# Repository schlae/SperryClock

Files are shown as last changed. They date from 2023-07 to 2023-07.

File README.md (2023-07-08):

# Nine Digit Sperry Neon Display Clock

Here's a cute little clock I designed that uses a Sperry neon display -- sometimes known as a Panaplex display. Please note this is not a fully completed project. Although I fabbed out boards and got the display working, I never got around to finishing the firmware.

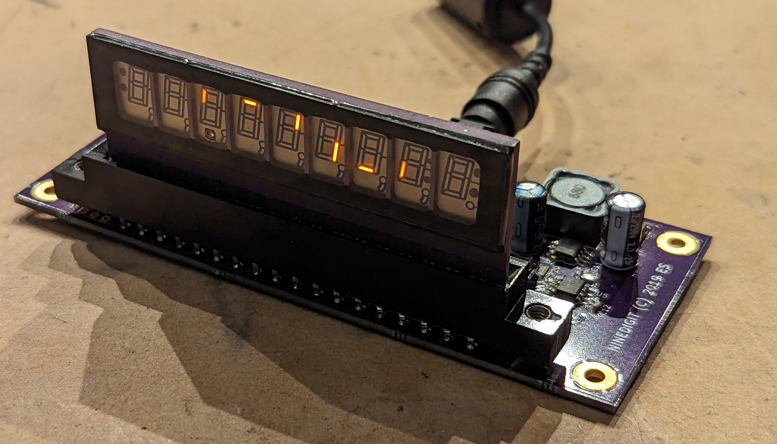
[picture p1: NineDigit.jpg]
A small circuit board with a Panaplex display plugged in


The particular display in this clock is a Sperry SP-425-09, but the basic design will probably work with other Panaplex displays as well.

The brains of the operation is an ATMega328P with a 16MHz crystal. You can load it with the Arduino bootloader and write programs for it using the Arduino IDE, or you can program it directly using avr-gcc, AVR Libc, and avrdude.

[Here is the schematic.](https://github.com/schlae/SperryClock/blob/main/NineDigit.pdf)

The basic design uses 9 transistors to multiplex the segment signals to each of the digits in the display. Typical Panaplex displays must be multiplexed otherwise the segment cathode material will start to plate out and darken the display, so avoid operating the display with just a single digit turned on continuously.

The [firmware](https://github.com/schlae/SperryClock/blob/main/NineDigit.ino) is incomplete but does include all the code required to drive the multiplexed display.

Still to be done:

* Driver for the DS3231
* Button handling
* Clock logic 

## Fabrication and Assembly Notes
This is a two-layer board, outer dimensions of 115mm x 50mm. 

The Sperry display should be installed in a socket. I've specified a part from EDAC but you might be able to find a cheaper one. The pin spacing is 0.156" (3.96mm).

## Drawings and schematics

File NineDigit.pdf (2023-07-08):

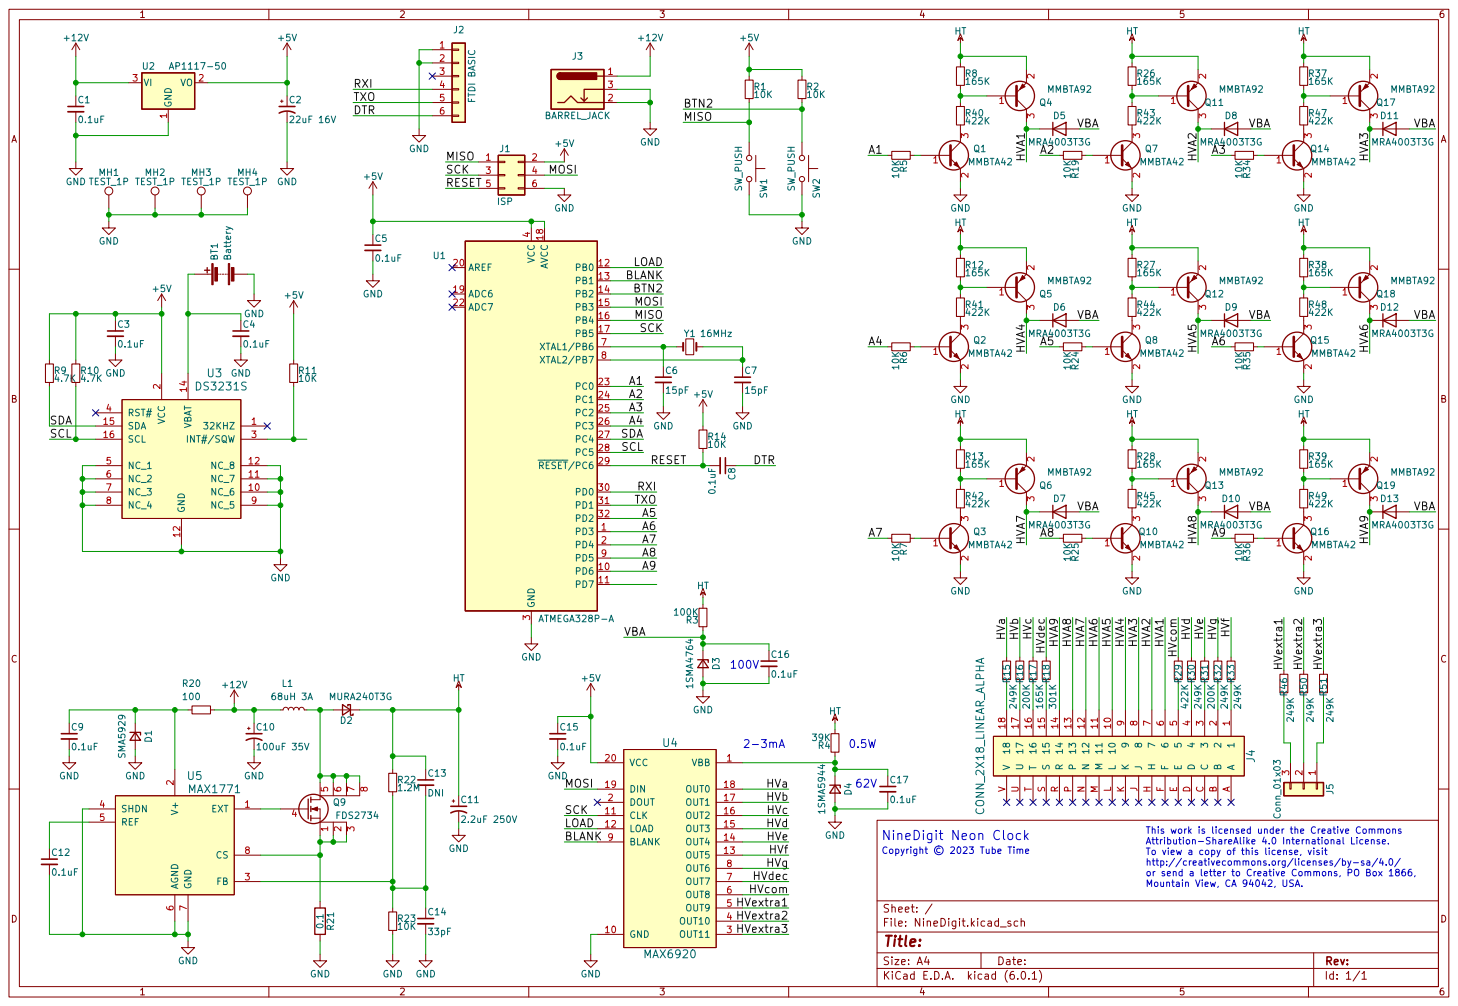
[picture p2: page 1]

http://creativecommons.org/licenses/by-sa/4.0/ or send a letter to Creative Commons, PO Box 1866, Mountain View, CA 94042, USA. þÿCopyright © 2023 Tube Time 0.5W

2 FB 3 SHDN 4 REF 5 AGND

This work is licensed under the Creative Commons Attribution-ShareAlike 4.0 International License. To view a copy of this license, visit

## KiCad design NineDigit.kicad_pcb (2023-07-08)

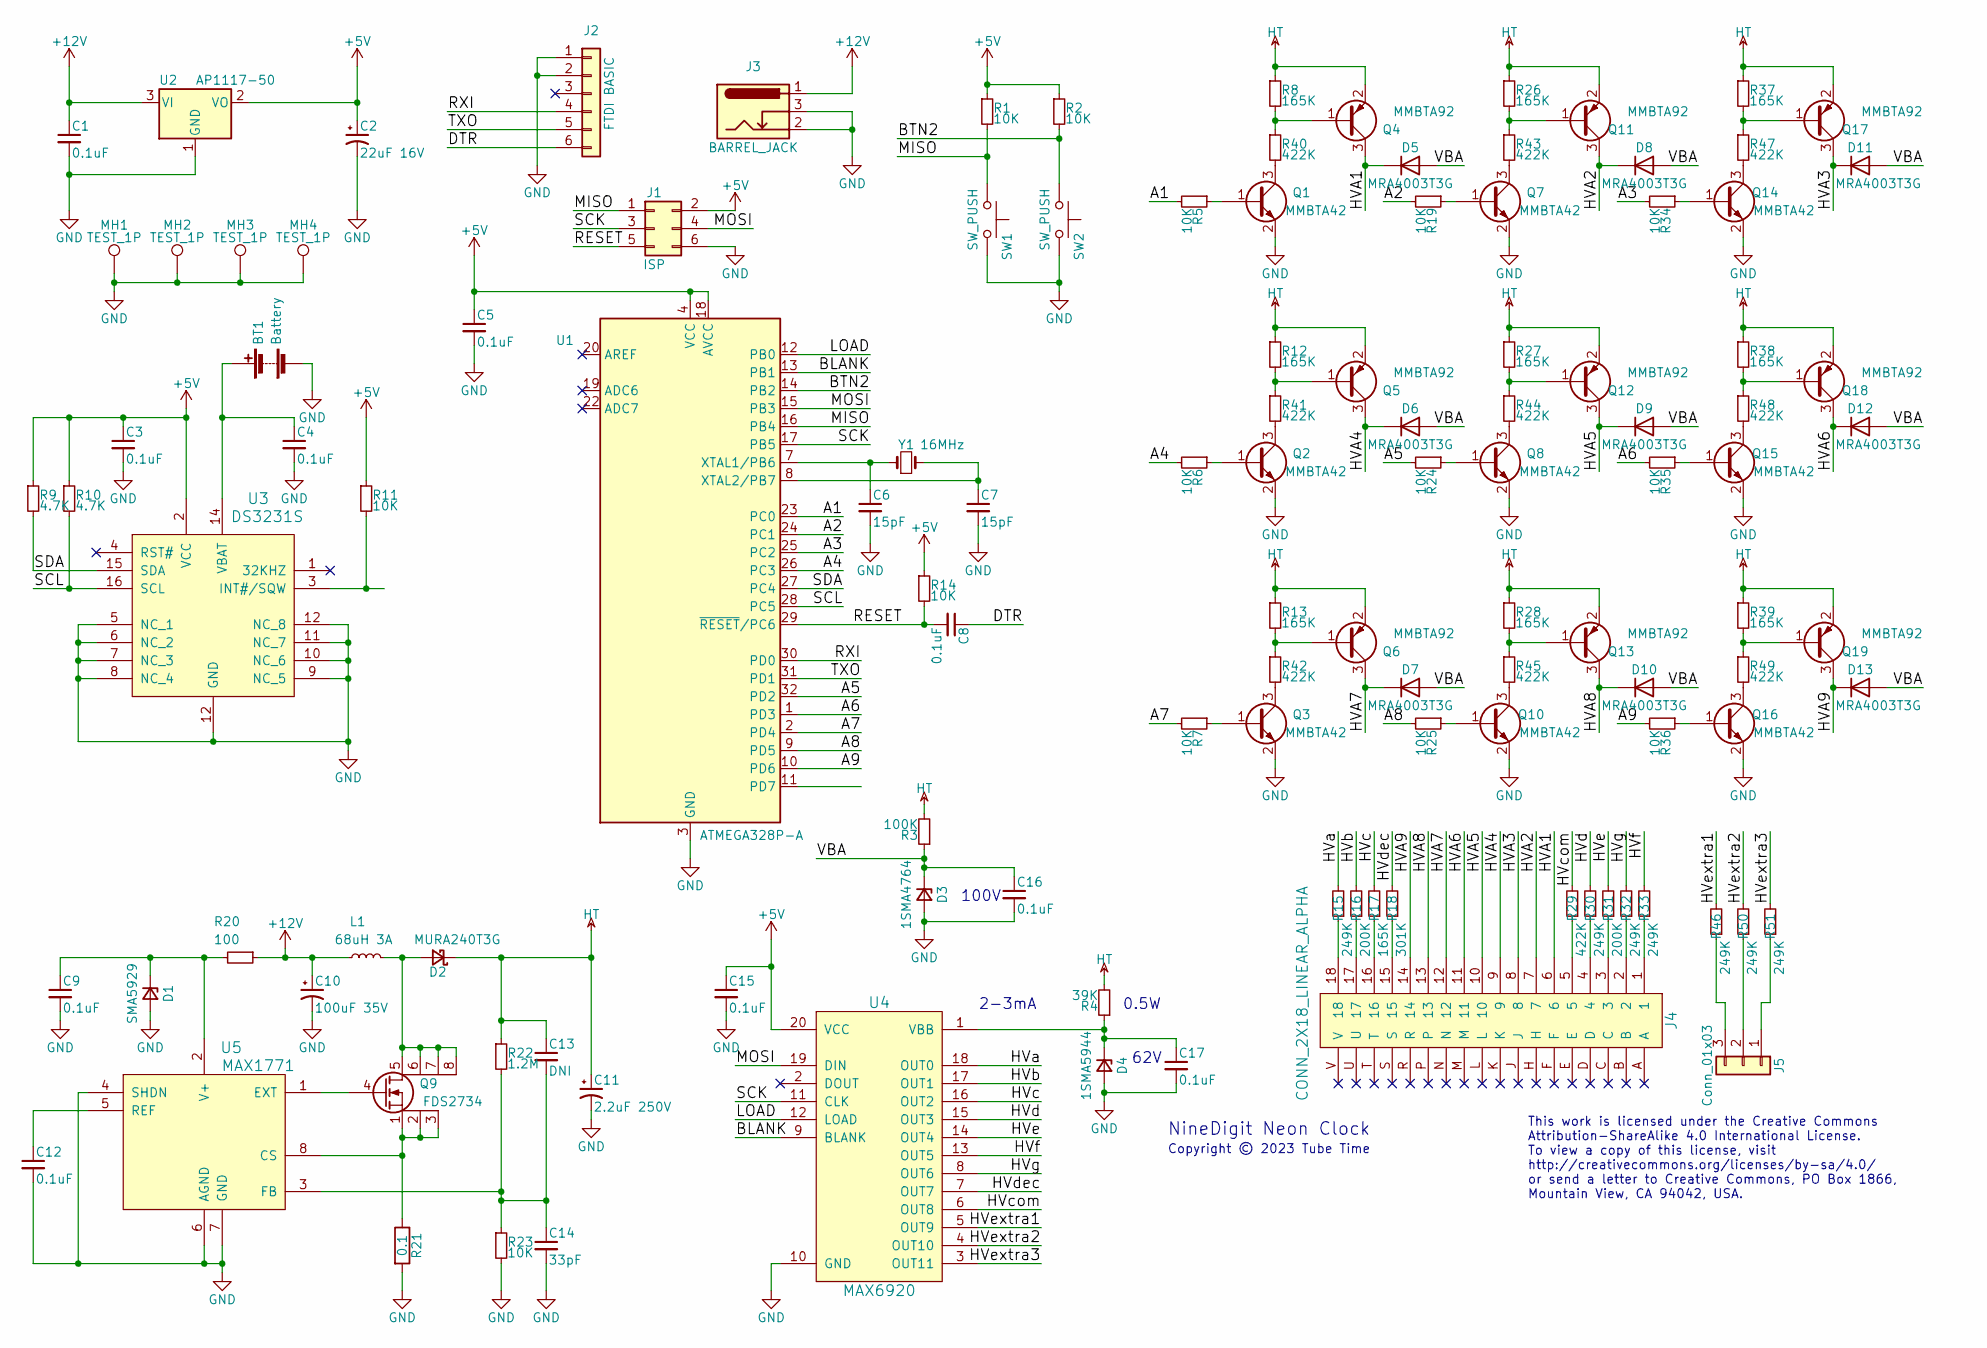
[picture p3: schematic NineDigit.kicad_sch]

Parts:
BT1: Battery; CR2032H
C1, C3, C4, C5, C8, C9, C12, C15: 0.1uF; CAPC1608X100
C2: 22uF 16V; CAPAE250P630X1100
C6, C7: 15pF; CAPC1608X100
C10: 100uF 35V; CAPAE250P630X1100
C11: 2.2uF 250V; CAPAE250P630X1100; MFG_PN 647-ULD2E2R2MED1TD
C13: DNI; CAPC2012X55
C14: 33pF; CAPC1608X100
C16, C17: 0.1uF; CAPC3225X110; Mouser 710-885342208004
D1: SMA5929; DIOM5226X210; Mouser 821-1SMA5929R3
D2: MURA240T3G; DIOM5226X210; Mouser 863-MURA240T3G
D3: 1SMA4764; DIOM5226X210; Mouser 821-1SMA4764R3
D4: 1SMA5944; DIOM5226X210; Mouser 821-1SMA5944R3
D5, D6, D7, D8, D9, D10, D11, D12, D13: MRA4003T3G; DIOM5226X210
J1: ISP; Pin_Header_Straight_2x03_Pitch2.54mm_SMD
J2: FTDI BASIC; Pin_Header_Straight_1x06_Pitch2.54mm
J3: BARREL_JACK; BarrelJack_Horizontal
J4: CONN_2X18_LINEAR_ALPHA; EDAC_357-036-520-208
J5: Conn_01x03; Pin_Header_Straight_1x03_Pitch2.54mm
L1: 68uH 3A; INDM125125X600; MFG_PN 652-SRR1260A-680M
MH1, MH2, MH3, MH4: TEST_1P; MountingHole_3.2mm_M3_Pad
Q1, Q2, Q3, Q7, Q8, Q10, Q14, Q15, Q16: MMBTA42; SOT95P230X117-3
Q4, Q5, Q6, Q11, Q12, Q13, Q17, Q18, Q19: MMBTA92; SOT95P230X117-3
Q9: FDS2734; SOP127P620X175-8; Mouser 512-FDS2734
R1, R2, R5, R6, R7, R11, R14, R19, R23, R24, R25, R34, R35, R36: 10K; RESC1608X55
R3: 100K; RESC3216X70
R4: 39K; RESC3216X70
R8, R12, R13, R17, R26, R27, R28, R37, R38, R39: 165K; RESC3216X70; Mouser 71-CRCW1206-165K-E3
R9, R10: 4.7K; RESC1608X55
R15, R30, R32, R33, R46, R50, R51: 249K; RESC3216X70; Mouser 71-CRCW1206-249K-E3
R16, R31: 200K; RESC3216X70; Mouser 71-CRCW1206-200K-E3
R18: 301K; RESC3216X70; Mouser 71-CRCW1206-301K-E3
R20: 100; RESC2012X55
R21: 0.1; RESC2012X55; Mouser 660-UR73V2ATTDR100F
R22: 1.2M; RESC3216X70; Mouser 660-HV732BTTD1204F
R29, R40, R41, R42, R43, R44, R45, R47, R48, R49: 422K; RESC3216X70; Mouser 71-CRCW1206-422K-E3
SW1, SW2: SW_PUSH; SW_PUSH_6mm
U1: ATMEGA328P-A; TQFP80P900X900X120-32
U2: AP1117-50; SOT230P700X170-3
U3: DS3231S; SOP127P1065X265-16
U4: MAX6920; SOP127P1065X265-20; Mouser 700-MAX6920AWP
U5: MAX1771; SOP127P620X175-8
Y1: 16MHz; XTAL500X320X120-2

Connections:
+5V: C2.1, C3.1, C5.1, C15.1, J1.2, R1.1, R2.1, R9.1, R10.1, R11.1, R14.1, U1.4 (VCC), U1.6 (VCC), U1.18 (AVCC), U2.2 (VO), U3.2 (VCC), U4.20 (VCC)
+12V: C1.1, C10.1, J3.1, L1.1, R20.1, U2.3 (VI)
/A1: R5.2, U1.23 (PC0)
/A2: R19.2, U1.24 (PC1)
/A3: R34.2, U1.25 (PC2)
/A4: R6.2, U1.26 (PC3)
/A5: R24.2, U1.32 (PD2)
/A6: R35.2, U1.1 (PD3)
/A7: R7.2, U1.2 (PD4)
/A8: R25.2, U1.9 (PD5)
/A9: R36.2, U1.10 (PD6)
/BLANK: U1.13 (PB1), U4.9 (BLANK)
/BTN2: R2.2, SW2.1, U1.14 (PB2)
/DTR: C8.1, J2.6
/HVA1: D5.1 (K), J4.6, Q4.3 (C)
/HVA2: D8.1 (K), J4.7, Q11.3 (C)
/HVA3: D11.1 (K), J4.8, Q17.3 (C)
/HVA4: D6.1 (K), J4.9, Q5.3 (C)
/HVA5: D9.1 (K), J4.10, Q12.3 (C)
/HVA6: D12.1 (K), J4.11, Q18.3 (C)
/HVA7: D7.1 (K), J4.12, Q6.3 (C)
/HVA8: D10.1 (K), J4.13, Q13.3 (C)
/HVA9: D13.1 (K), J4.14, Q19.3 (C)
/HVa: R15.2, U4.18 (OUT0)
/HVb: R16.2, U4.17 (OUT1)
/HVc: R17.2, U4.16 (OUT2)
/HVcom: R29.2, U4.6 (OUT8)
/HVd: R30.2, U4.15 (OUT3)
/HVdec: R18.2, U4.7 (OUT7)
/HVe: R31.2, U4.14 (OUT4)
/HVextra1: R46.2, U4.5 (OUT9)
/HVextra2: R50.2, U4.4 (OUT10)
/HVextra3: R51.2, U4.3 (OUT11)
/HVf: R33.2, U4.13 (OUT5)
/HVg: R32.2, U4.8 (OUT6)
/LOAD: U1.12 (PB0), U4.12 (LOAD)
/MISO: J1.1, R1.2, SW1.1, U1.16 (PB4)
/MOSI: J1.4, U1.15 (PB3), U4.19 (DIN)
/RESET: C8.2, J1.5, R14.2, U1.29 (~RESET/PC6)
/RXI: J2.4, U1.30 (PD0)
/SCK: J1.3, U1.17 (PB5), U4.11 (CLK)
/SCL: R10.2, U1.28 (PC5), U3.16 (SCL)
/SDA: R9.2, U1.27 (PC4), U3.15 (SDA)
/TXO: J2.5, U1.31 (PD1)
/VBA: C16.1, D3.1 (K), D5.2 (A), D6.2 (A), D7.2 (A), D8.2 (A), D9.2 (A), D10.2 (A), D11.2 (A), D12.2 (A), D13.2 (A), R3.1
GND: BT1.2 (-), C1.2, C2.2, C3.2, C4.2, C5.2, C6.2, C7.2, C9.2, C10.2, C11.2, C12.2, C14.2, C15.2, C16.2, C17.2, D1.2 (A), D3.2 (A), D4.2 (A), J1.6, J2.1, J2.2, J3.2, J3.3, MH1.1, MH2.1, MH3.1, MH4.1, Q1.2 (E), Q2.2 (E), Q3.2 (E), Q7.2 (E), Q8.2 (E), Q10.2 (E), Q14.2 (E), Q15.2 (E), Q16.2 (E), R21.2, R23.2, SW1.2, SW2.2, U1.3 (GND), U1.5 (GND), U1.21 (GND), U2.1 (GND), U3.5 (NC_1), U3.6 (NC_2), U3.7 (NC_3), U3.8 (NC_4), U3.9 (NC_5), U3.10 (NC_6), U3.11 (NC_7), U3.12 (GND), U4.10 (GND), U5.4 (SHDN), U5.6 (AGND), U5.7 (GND)
HT: C11.1, C13.1, D2.1 (K), Q4.2 (E), Q5.2 (E), Q6.2 (E), Q11.2 (E), Q12.2 (E), Q13.2 (E), Q17.2 (E), Q18.2 (E), Q19.2 (E), R3.2, R4.2, R8.1, R12.1, R13.1, R22.1, R26.1, R27.1, R28.1, R37.1, R38.1, R39.1
unnamed: BT1.1 (+), C4.1, U3.14 (VBAT)
unnamed: C6.1, U1.7 (XTAL1/PB6), Y1.1
unnamed: C7.1, U1.8 (XTAL2/PB7), Y1.2
unnamed: C9.1, D1.1 (K), R20.2, U5.2 (V+)
unnamed: C12.1, U5.5 (REF)
unnamed: C13.2, C14.1, R22.2, R23.1, U5.3 (FB)
unnamed: C17.1, D4.1 (K), R4.1, U4.1 (VBB)
unnamed: D2.2 (A), L1.2, Q9.5 (D1), Q9.6 (D2), Q9.7 (D3), Q9.8 (D4)
unnamed: J4.1, R33.1
unnamed: J4.2, R32.1
unnamed: J4.3, R31.1
unnamed: J4.4, R30.1
unnamed: J4.5, R29.1
unnamed: J4.15, R18.1
unnamed: J4.16, R17.1
unnamed: J4.17, R16.1
unnamed: J4.18, R15.1
unnamed: J5.1, R51.1
unnamed: J5.2, R50.1
unnamed: J5.3, R46.1
unnamed: Q1.1 (B), R5.1
unnamed: Q1.3 (C), R40.2
unnamed: Q2.1 (B), R6.1
unnamed: Q2.3 (C), R41.2
unnamed: Q3.1 (B), R7.1
unnamed: Q3.3 (C), R42.2
unnamed: Q4.1 (B), R8.2, R40.1
unnamed: Q5.1 (B), R12.2, R41.1
unnamed: Q6.1 (B), R13.2, R42.1
unnamed: Q7.1 (B), R19.1
unnamed: Q7.3 (C), R43.2
unnamed: Q8.1 (B), R24.1
unnamed: Q8.3 (C), R44.2
unnamed: Q9.1 (S1), Q9.2 (S2), Q9.3 (S3), R21.1, U5.8 (CS)
unnamed: Q9.4 (G), U5.1 (EXT)
unnamed: Q10.1 (B), R25.1
unnamed: Q10.3 (C), R45.2
unnamed: Q11.1 (B), R26.2, R43.1
unnamed: Q12.1 (B), R27.2, R44.1
unnamed: Q13.1 (B), R28.2, R45.1
unnamed: Q14.1 (B), R34.1
unnamed: Q14.3 (C), R47.2
unnamed: Q15.1 (B), R35.1
unnamed: Q15.3 (C), R48.2
unnamed: Q16.1 (B), R36.1
unnamed: Q16.3 (C), R49.2
unnamed: Q17.1 (B), R37.2, R47.1
unnamed: Q18.1 (B), R38.2, R48.1
unnamed: Q19.1 (B), R39.2, R49.1
unnamed: R11.2, U3.3 (INT#/SQW)

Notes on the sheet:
This work is licensed under the Creative Commons Attribution-ShareAlike 4.0 International License. To view a copy of this license, visit http://creativecommons.org/licenses/by-sa/4.0/ or send a letter to Creative Commons, PO Box 1866, Mountain View, CA 94042, USA.
0.5W
2-3mA
62V
NineDigit Neon Clock
100V
Copyright © 2023 Tube Time

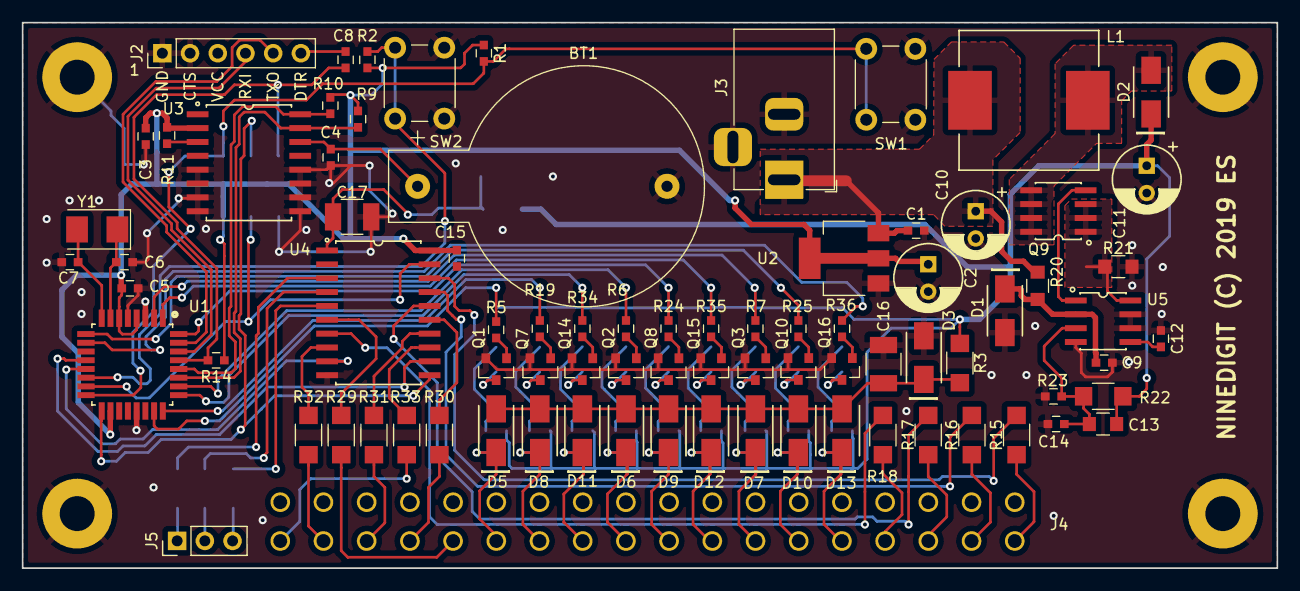
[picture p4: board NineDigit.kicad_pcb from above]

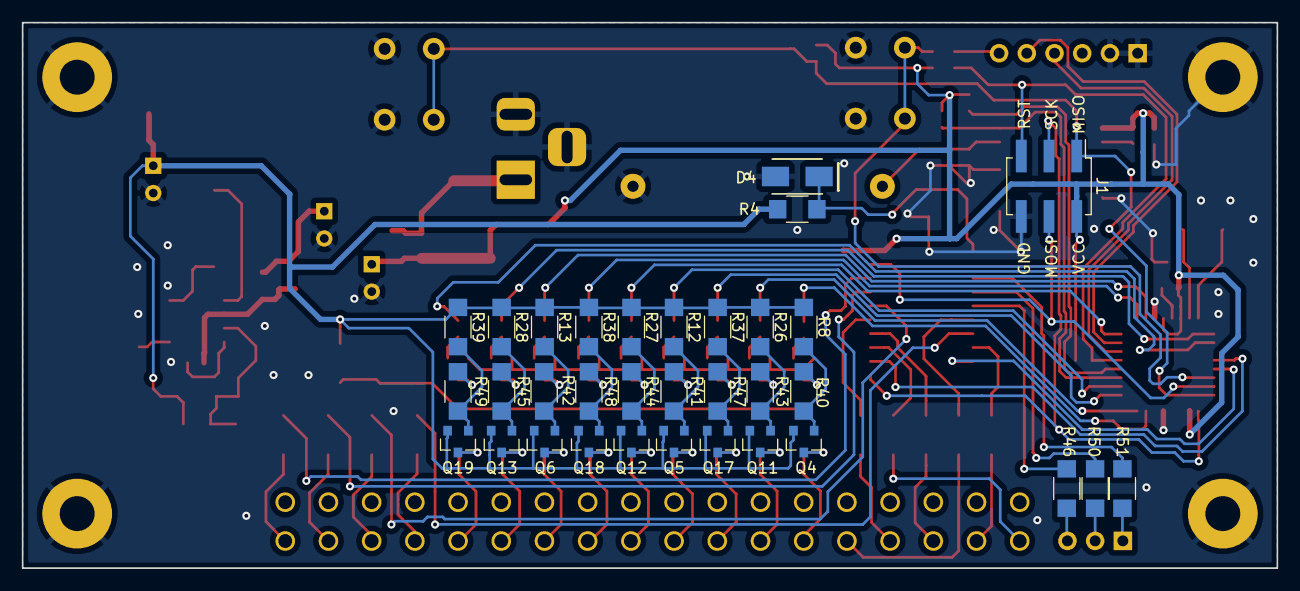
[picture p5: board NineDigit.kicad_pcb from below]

Board: 2 copper layers, 115.0 x 50.0 mm, 119 parts (33 on the bottom side), 97 nets.

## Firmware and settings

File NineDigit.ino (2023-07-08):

#include <stdint.h>
#include <avr/io.h>
#include <avr/interrupt.h>

#define DELAY_ANODE_DECAY 10
#define MUX_RATE (65535L - 16000000L/64/2000)

uint16_t displayContents[9] = {0};
uint8_t currentDigit = 0;

//    --0x01--
//   |        |
//  0x20     0x02
//   |        |
//    --0x40--
//   |        |
//  0x10     0x04
//   |        |
//    --0x08--
//              . (0x80) , (0x100)

uint8_t digs[6] = {0x1, 0x2, 0x4, 0x8, 0x10, 0x20};
uint8_t dig_start = 0;

const uint8_t digitLookup[10] = {0x3f, 0x06, 0x5b, 0x4f, 0x66,
                           0x6d, 0x7d, 0x07, 0x7f, 0x6f};

//                                @     A     b     C     d     E     F     g
const uint8_t alphaLookup[32] = {0x5f, 0x77, 0x7c, 0x39, 0x5e, 0x79, 0x71, 0x6F,
//                                H     I     J     K     L     M     n     O
                                 0x76, 0x06, 0x0e, 0x00, 0x38, 0x37, 0x54, 0x3f,
//                                P     Q     r     S     T     U     V     W
                                 0x73, 0x67, 0x50, 0x6d, 0x78, 0x3e, 0x3e, 0x00,
//                                X     y     Z     [     \     ]     ^     _
                                 0x00, 0x6e, 0x5b, 0x39, 0x64, 0x0f, 0x00, 0x08};

void printDigit(uint8_t value, uint8_t digit) {
  displayContents[digit] = (displayContents[digit] & 0x180) | digitLookup[value];
}

void printAlpha(char c, uint8_t digit) {
  if (c >= 0x40 && c <= 0x5F) {
    displayContents[digit] = (displayContents[digit] & 0x180) | alphaLookup[c-0x40];
  }
} 

// Write to MAX6920
void writeMAX(uint16_t value) {
  int i;
  for (i = 11; i >= 0; i--) {
    if ((value >> i) & 1) {
      PORTB |= _BV(3);
    } else {
      PORTB &= ~_BV(3);
    }
    PORTB |= _BV(5);
    PORTB &= ~_BV(5);
  }
  PORTB |= _BV(0);
  PORTB &= ~_BV(0);
}

void setupMAX() {
  DDRB |= _BV(0) | _BV(1) | _BV(3) | _BV(5);
}

void setupMux() {
  DDRC |= _BV(0) | _BV(1) | _BV(2) | _BV(3);
  DDRD |= _BV(2) | _BV(3) | _BV(4) | _BV(5) | _BV(6);
  PORTC = 0;
  PORTD = 0;
}

void clearDigit() 
{
  PORTC &= ~(_BV(0) | _BV(1) | _BV(2) | _BV(3));
  PORTD &= ~(_BV(2) | _BV(3) | _BV(4) | _BV(5) | _BV(6));  
}

void doDigit(uint8_t digit) {
  if (digit <= 3) {
    PORTC |= _BV(digit);
  } else {
    PORTD |= _BV(digit - 2);
  }
}

ISR (TIMER1_OVF_vect)
{
  currentDigit++;
  if (currentDigit > 8) currentDigit = 0;
  clearDigit();
  delayMicroseconds(DELAY_ANODE_DECAY);
  writeMAX(~displayContents[currentDigit]);
  doDigit(currentDigit);
  TCNT1 = MUX_RATE;
}

void setup() {
  // put your setup code here, to run once:
  Serial.begin(115200);
  setupMux();
  setupMAX();
  TCNT1 = MUX_RATE;
  TCCR1A = 0x00; // No output pins
  TCCR1B = (1 << CS10) | (1 << CS11); // CLKIO / 64
  TIMSK1 = (1 << TOIE1);
  sei();

  for (int i = 0; i < 9; i++) {
    displayContents[i] = 0x1AA;
  }
}

void loop() {
  
  // put your main code here, to run repeatedly:
  delayMicroseconds(1000);
  #if 0
  char st[] = "@TUBETIME";
  for (int i = 0; i < 10; i++) {
    //printDigit(i, i);
    printAlpha(st[i], i);
  }
  #endif
  for (int i = 0; i < 10; i++) {
    displayContents[i] = digs[(dig_start + i) % 6];
  }
  dig_start++;
  delay(50);
}

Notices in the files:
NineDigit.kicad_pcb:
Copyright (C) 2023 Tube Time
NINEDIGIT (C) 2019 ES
